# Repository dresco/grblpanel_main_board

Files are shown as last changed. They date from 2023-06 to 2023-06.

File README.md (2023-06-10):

# grblPANEL reference board

KiCad implementation of a grblPANEL control board, with the following features;
- up to 88 input keys
- up to 4 quadrature encoders
- display output (reference design using a 3.5" ILI9488 panel)
- Modbus and CAN bus (WIP) connectivity to grblHAL controller
- SWD connector (2x5 1.27mm) for programming and debugging
- USB C interface for programming and configuration (WIP)
- ESD protection on all user connections
- 5-12V DC power input - with reverse polarity, undervoltage, overvoltage, and overcurrent protection

The control board uses the following high level components;
- STM32G0 MCU running at 64MHz
- TI SN65HVD230 CAN transceiver
- TI THVD1406 Modbus transceiver
- Analog Devices ADP5589 I/O expander
- Analog Devices MAX17612A power protection IC

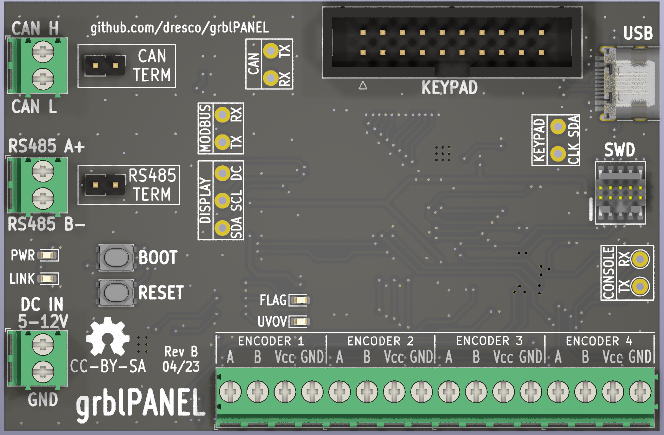
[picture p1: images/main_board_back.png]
back

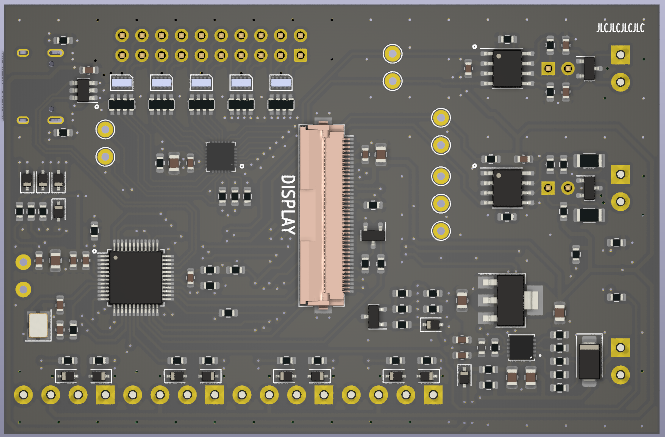
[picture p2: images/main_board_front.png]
front


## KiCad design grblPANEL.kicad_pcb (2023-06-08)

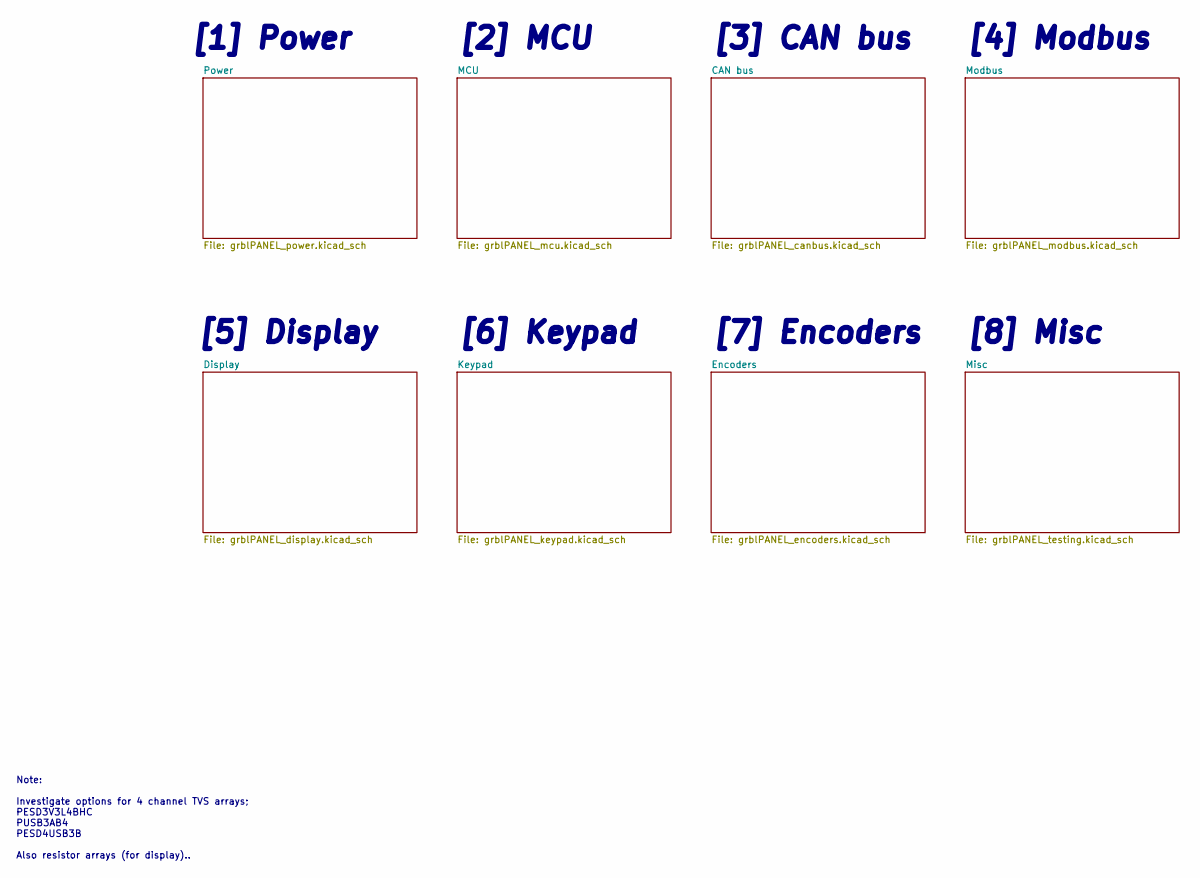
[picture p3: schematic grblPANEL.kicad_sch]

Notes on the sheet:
[2] MCU
[3] CAN bus
[1] Power
[8] Misc
Note: Investigate options for 4 channel TVS arrays; PESD3V3L4BHC PUSB3AB4 PESD4USB3B Also resistor arrays (for display)..
[6] Keypad
[4] Modbus
[5] Display
[7] Encoders

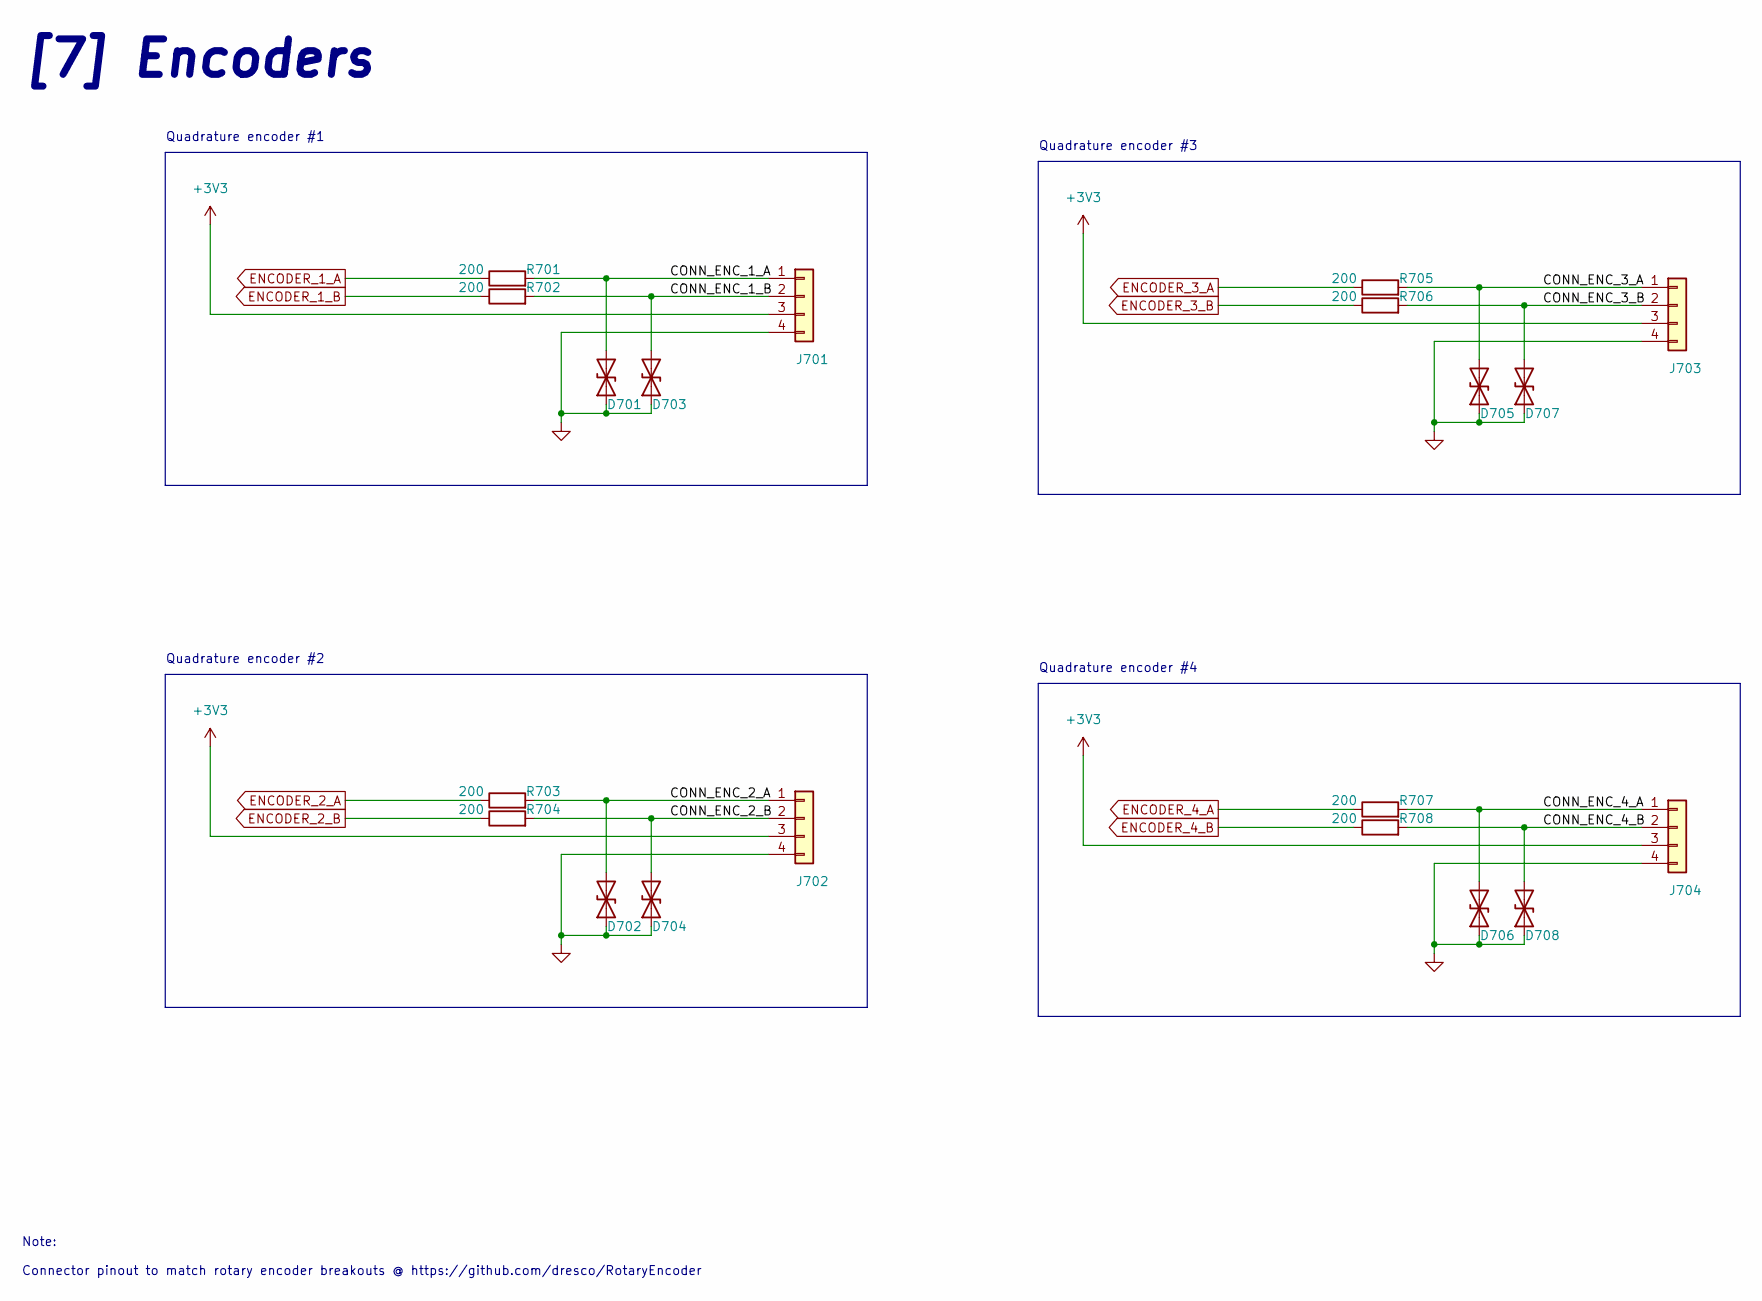
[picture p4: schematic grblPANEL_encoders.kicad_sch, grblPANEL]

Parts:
D701, D702, D703, D704, D705, D706, D707, D708: D_TVS; D_SOD-323
J701, J702, J703, J704: Conn_01x04; TerminalBlock_Phoenix_PT-1,5-4-3.5-H_1x04_P3.50mm_Horizontal
R701, R702, R703, R704, R705, R706, R707, R708: 200; R_0603_1608Metric

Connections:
+3V3: J701.3, J702.3, J703.3, J704.3; also elsewhere on the board
/Encoders/CONN_ENC_1_A: D701.2 (A2), J701.1, R701.2
/Encoders/CONN_ENC_1_B: D703.2 (A2), J701.2, R702.2
/Encoders/CONN_ENC_2_A: D702.2 (A2), J702.1, R703.2
/Encoders/CONN_ENC_2_B: D704.2 (A2), J702.2, R704.2
/Encoders/CONN_ENC_3_A: D705.2 (A2), J703.1, R705.2
/Encoders/CONN_ENC_3_B: D707.2 (A2), J703.2, R706.2
/Encoders/CONN_ENC_4_A: D706.2 (A2), J704.1, R707.2
/Encoders/CONN_ENC_4_B: D708.2 (A2), J704.2, R708.2
ENCODER_1_A: R701.1; also elsewhere on the board
ENCODER_1_B: R702.1; also elsewhere on the board
ENCODER_2_A: R703.1; also elsewhere on the board
ENCODER_2_B: R704.1; also elsewhere on the board
ENCODER_3_A: R705.1; also elsewhere on the board
ENCODER_3_B: R706.1; also elsewhere on the board
ENCODER_4_A: R707.1; also elsewhere on the board
ENCODER_4_B: R708.1; also elsewhere on the board
GND: D701.1 (A1), D702.1 (A1), D703.1 (A1), D704.1 (A1), D705.1 (A1), D706.1 (A1), D707.1 (A1), D708.1 (A1), J701.4, J702.4, J703.4, J704.4; also elsewhere on the board

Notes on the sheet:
Quadrature encoder #3
Quadrature encoder #1
[7] Encoders
Quadrature encoder #4
Quadrature encoder #2
Note: Connector pinout to match rotary encoder breakouts @ https://github.com/dresco/RotaryEncoder

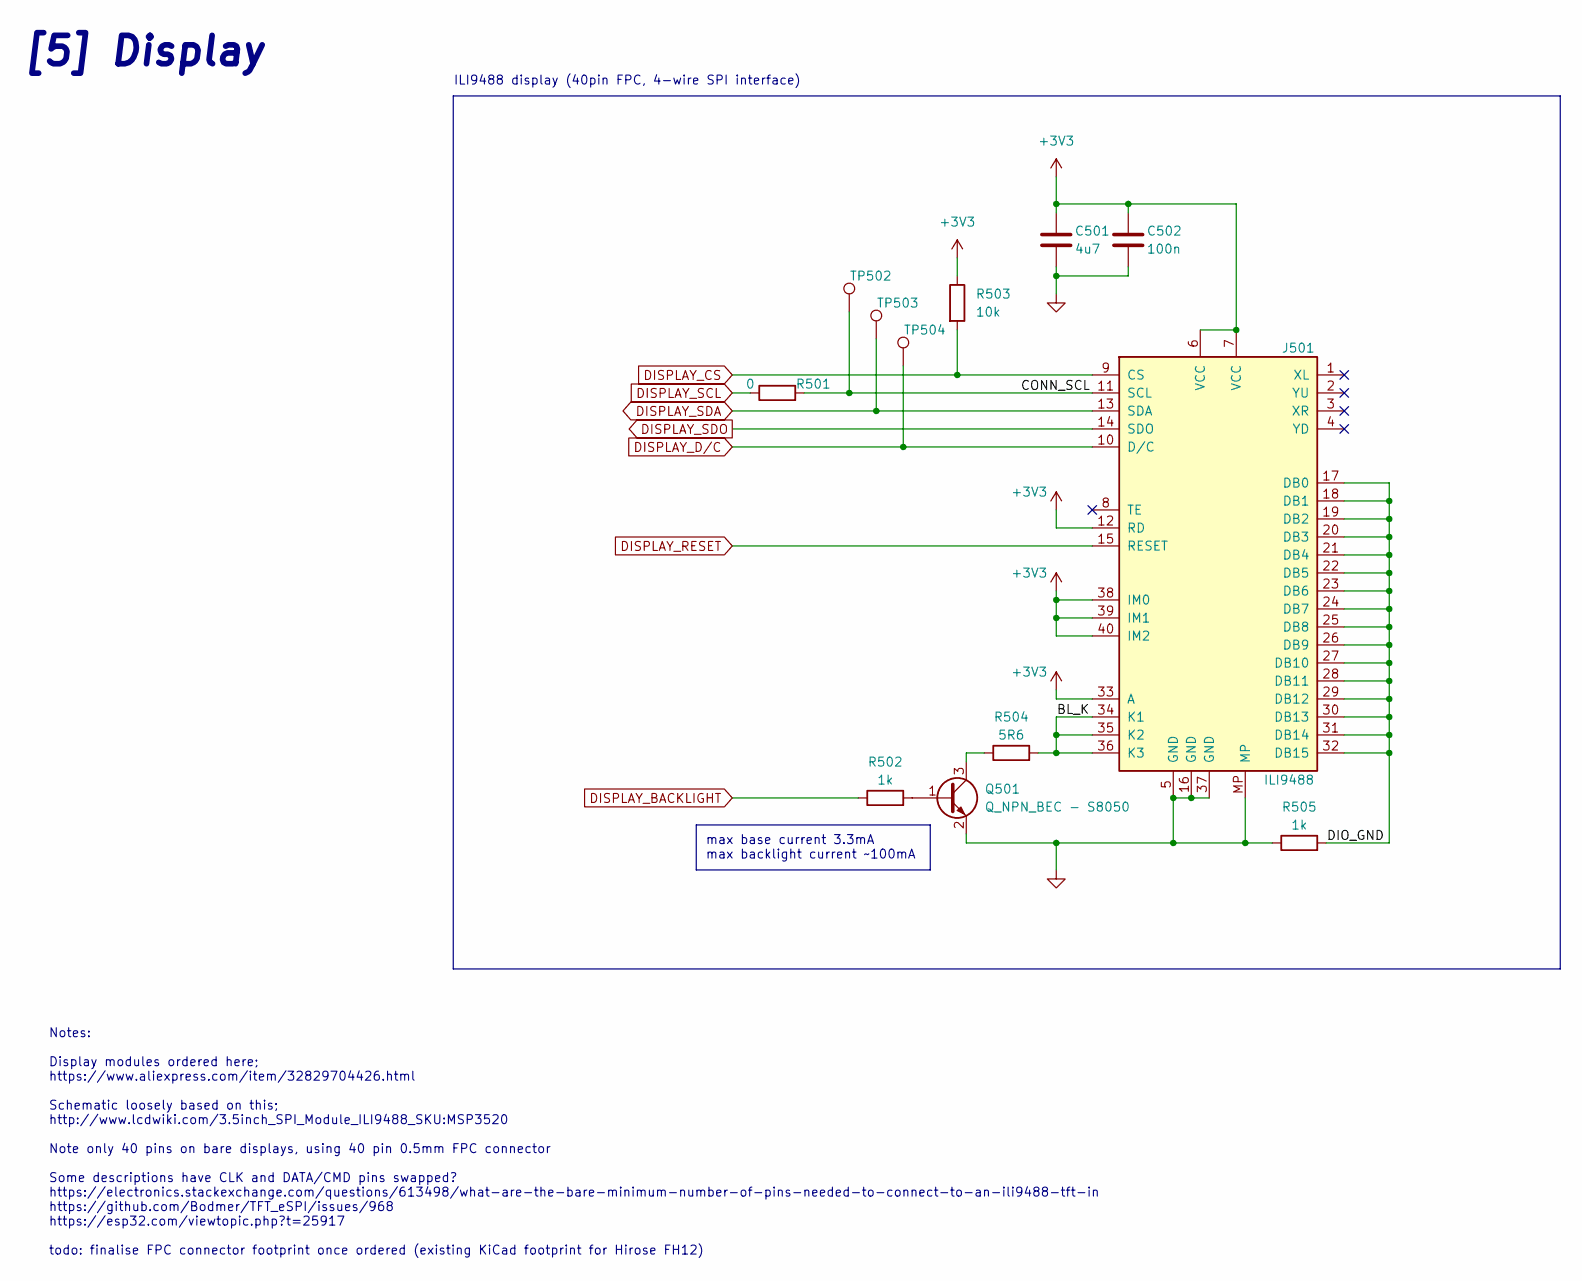
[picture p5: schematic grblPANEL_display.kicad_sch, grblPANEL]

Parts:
C501: 4u7; C_0805_2012Metric
C502: 100n; C_0603_1608Metric
J501: ILI9488; Hirose_FH12-40S-0.5SH_1x40-1MP_P0.50mm_Horizontal
Q501: Q_NPN_BEC - S8050; SOT-23
R501: 0; R_0603_1608Metric
R502, R505: 1k; R_0603_1608Metric
R503: 10k; R_0603_1608Metric
R504: 5R6; R_0603_1608Metric
TP502, TP503, TP504: TestPoint; TestPoint_THTPad_D2.0mm_Drill1.0mm

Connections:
+3V3: C501.1, C502.1, J501.6 (VCC), J501.7 (VCC), J501.12 (RD), J501.33 (A), J501.38 (IM0), J501.39 (IM1), J501.40 (IM2), R503.1; also elsewhere on the board
/Display/BL_K: J501.34 (K1), J501.35 (K2), J501.36 (K3), R504.2
/Display/CONN_SCL: J501.11 (SCL), R501.2, TP502.1
/Display/DIO_GND: J501.17 (DB0), J501.18 (DB1), J501.19 (DB2), J501.20 (DB3), J501.21 (DB4), J501.22 (DB5), J501.23 (DB6), J501.24 (DB7), J501.25 (DB8), J501.26 (DB9), J501.27 (DB10), J501.28 (DB11), J501.29 (DB12), J501.30 (DB13), J501.31 (DB14), J501.32 (DB15), R505.2
DISPLAY_BACKLIGHT: R502.1; also elsewhere on the board
DISPLAY_CS: J501.9 (CS), R503.2; also elsewhere on the board
DISPLAY_D/C: J501.10 (D/C), TP504.1; also elsewhere on the board
DISPLAY_RESET: J501.15 (RESET); also elsewhere on the board
DISPLAY_SCL: R501.1; also elsewhere on the board
DISPLAY_SDA: J501.13 (SDA), TP503.1; also elsewhere on the board
DISPLAY_SDO: J501.14 (SDO); also elsewhere on the board
GND: C501.2, C502.2, J501.5 (GND), J501.16 (GND), J501.37 (GND), J501.MP, Q501.2 (E), R505.1; also elsewhere on the board
unnamed: Q501.1 (B), R502.2
unnamed: Q501.3 (C), R504.1

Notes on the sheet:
[5] Display
max base current 3.3mA max backlight current ~100mA
Notes: Display modules ordered here; https://www.aliexpress.com/item/32829704426.html Schematic loosely based on this; http://www.lcdwiki.com/3.5inch_SPI_Module_ILI9488_SKU:MSP3520 Note only 40 pins on bare displays, using 40 pin 0.5mm FPC connector Some descriptions have CLK and DATA/CMD pins swap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
ILI9488 display (40pin FPC, 4-wire SPI interface)

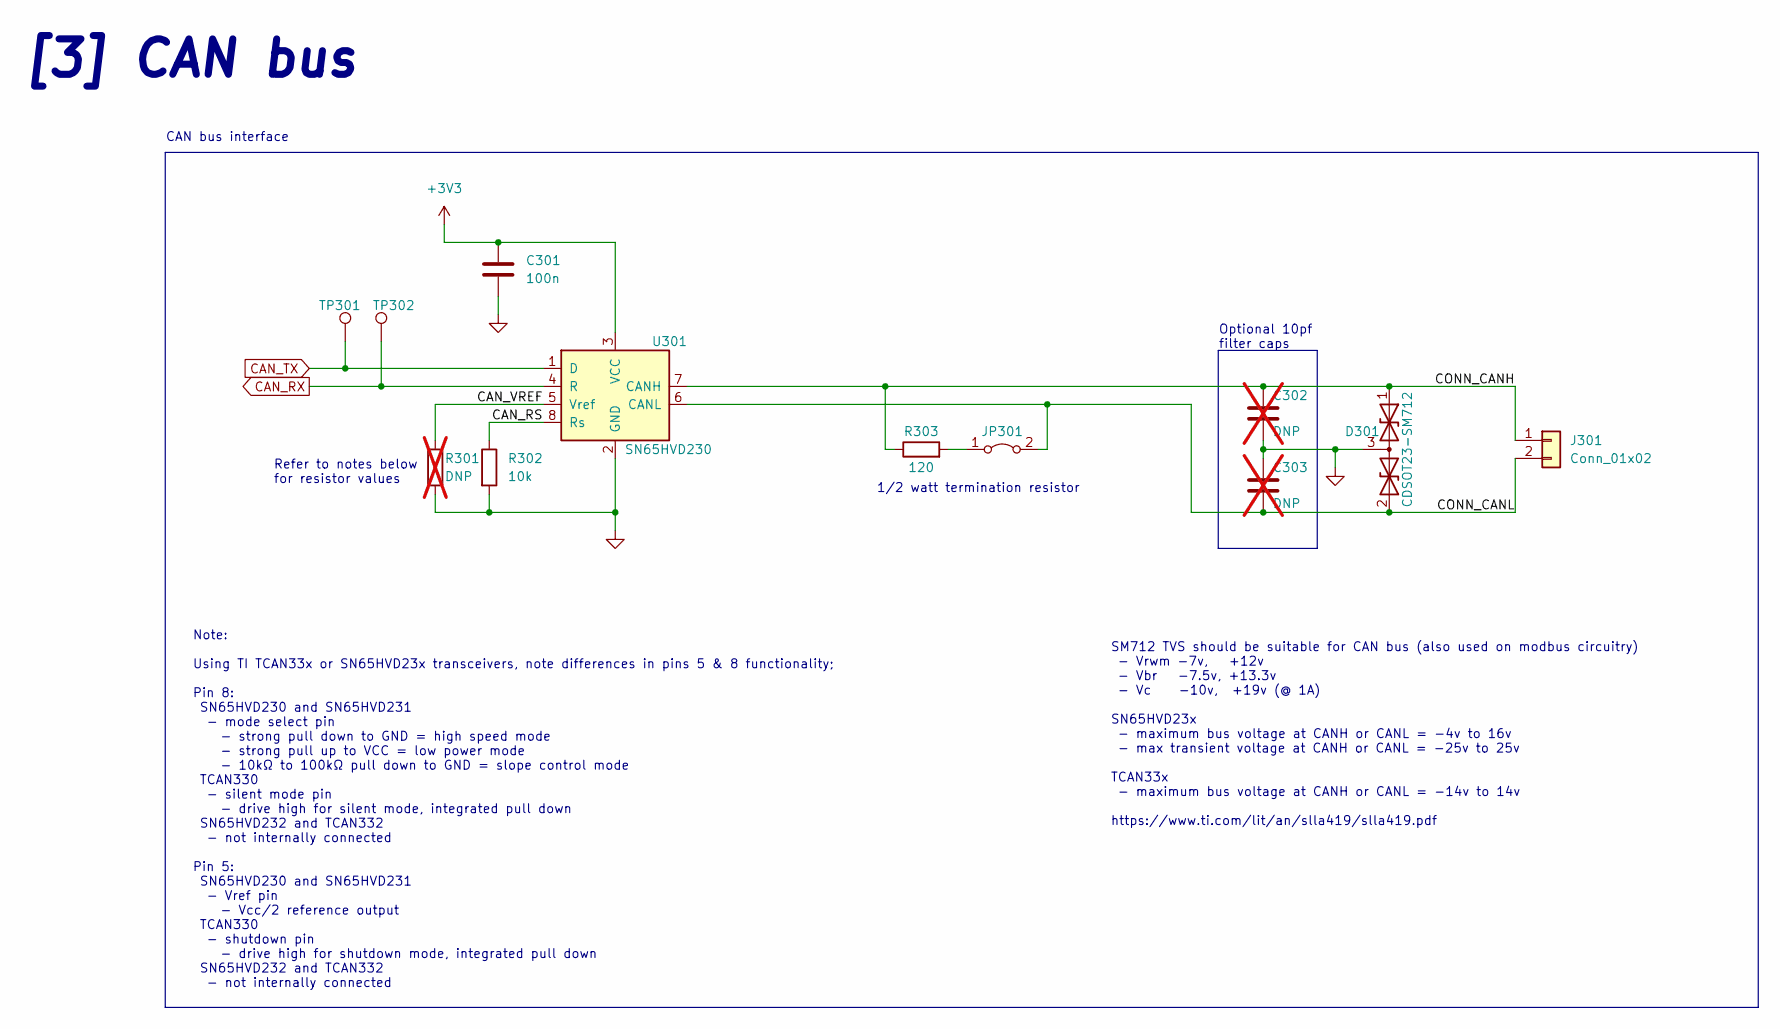
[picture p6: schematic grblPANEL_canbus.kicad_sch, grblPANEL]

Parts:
C301: 100n; C_0603_1608Metric
C302, C303: DNP; C_0603_1608Metric; not fitted
D301: CDSOT23-SM712; SOT-23
J301: Conn_01x02; TerminalBlock_Phoenix_PT-1,5-2-3.5-H_1x02_P3.50mm_Horizontal
JP301: Jumper_2_Bridged; PinHeader_1x02_P2.54mm_Vertical
R301: DNP; R_0603_1608Metric; not fitted
R302: 10k; R_0603_1608Metric
R303: 120; R_0603_1608Metric
TP301, TP302: TestPoint; TestPoint_THTPad_D2.0mm_Drill1.0mm
U301: SN65HVD230; SOIC-8_3.9x4.9mm_P1.27mm

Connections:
+3V3: C301.1, U301.3 (VCC); also elsewhere on the board
/CAN bus/CAN_RS: R302.1, U301.8 (Rs)
/CAN bus/CAN_VREF: R301.1, U301.5 (Vref)
/CAN bus/CONN_CANH: C302.1, D301.1 (A1), J301.1, R303.1, U301.7 (CANH)
/CAN bus/CONN_CANL: C303.2, D301.2 (A2), J301.2, JP301.2 (B), U301.6 (CANL)
CAN_RX: TP302.1, U301.4 (R); also elsewhere on the board
CAN_TX: TP301.1, U301.1 (D); also elsewhere on the board
GND: C301.2, C302.2, C303.1, D301.3 (common), R301.2, R302.2, U301.2 (GND); also elsewhere on the board
unnamed: JP301.1 (A), R303.2

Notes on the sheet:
Note: Using TI TCAN33x or SN65HVD23x transceivers, note differences in pins 5 & 8 functionality; Pin 8: SN65HVD230 and SN65HVD231 - mode select pin - strong pull down to GND = high speed mode - strong pull up to VCC = low power mode - 10kΩ to 100kΩ pull down to GND = slope control mode TCAN330 - si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
[3] CAN bus
CAN bus interface
SM712 TVS should be suitable for CAN bus (also used on modbus circuitry) - Vrwm -7v, +12v - Vbr -7.5v, +13.3v - Vc -10v, +19v (@ 1A) SN65HVD23x - maximum bus voltage at CANH or CANL = -4v to 16v - max transient voltage at CANH or CANL = -25v to 25v TCAN33x - maximum bus voltage at CANH or CANL = -1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
Refer to notes below for resistor values
1/2 watt termination resistor
Optional 10pf filter caps

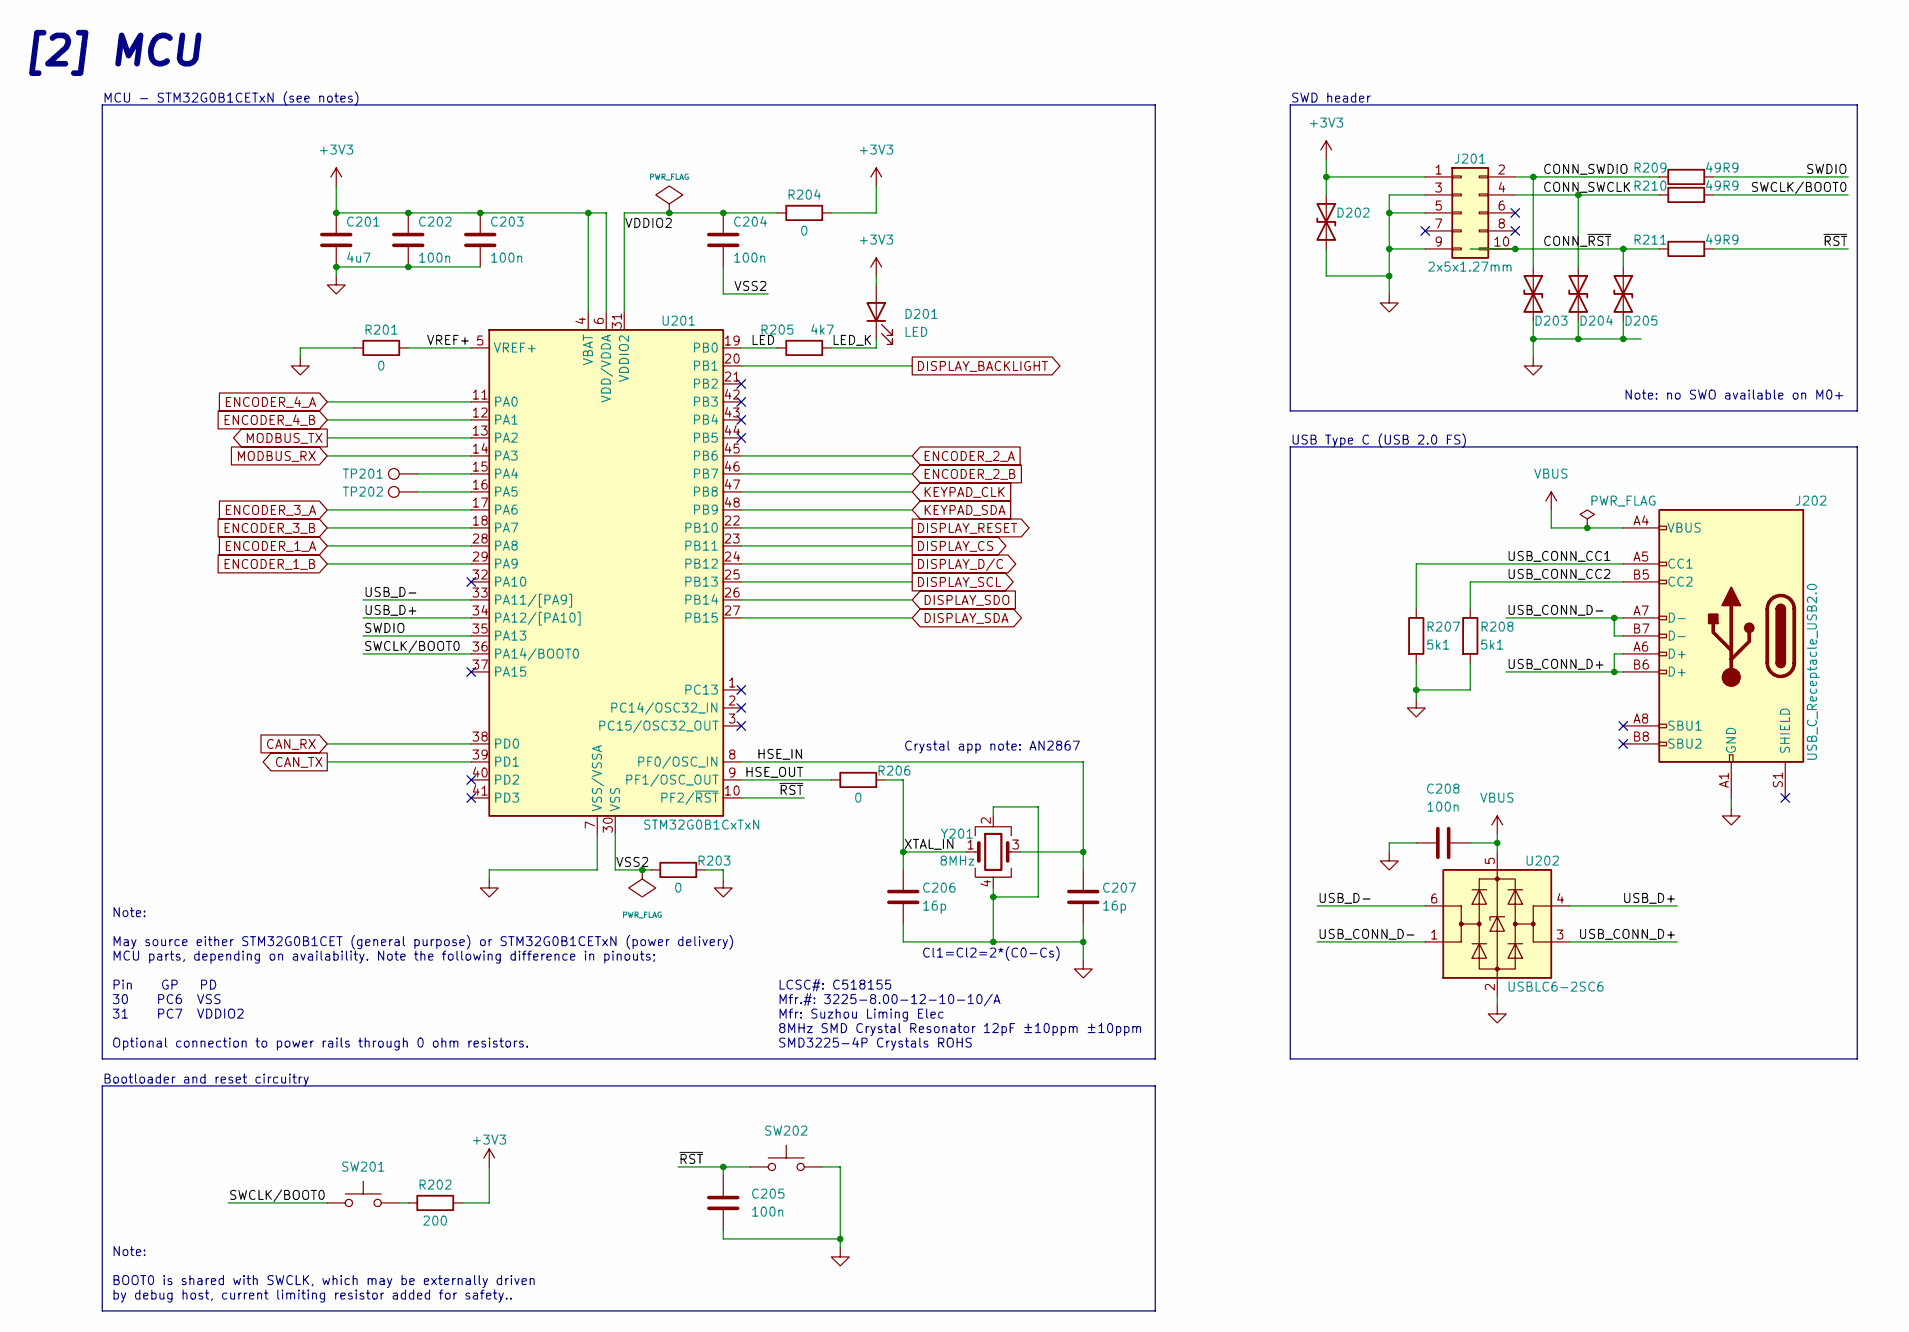
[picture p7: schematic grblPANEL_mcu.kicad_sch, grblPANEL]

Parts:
C201: 4u7; C_0805_2012Metric
C202, C203, C204, C205, C208: 100n; C_0603_1608Metric
C206, C207: 16p; C_0603_1608Metric
D201: LED; LED_0603_1608Metric
D202, D203, D204, D205: D_TVS; D_SOD-323
J201: 2x5x1.27mm; FTSH-105-01-L-DV-K
J202: USB_C_Receptacle_USB2.0; USB_C_Receptacle_HRO_TYPE-C-31-M-12
R201, R203, R204, R206: 0; R_0603_1608Metric
R202: 200; R_0603_1608Metric
R205: 4k7; R_0603_1608Metric
R207, R208: 5k1; R_0603_1608Metric
R209, R210, R211: 49R9; R_0603_1608Metric
SW201, SW202: SW_Push; SW_SPST_PTS810
TP201, TP202: TestPoint; TestPoint_THTPad_D2.0mm_Drill1.0mm
U201: STM32G0B1CxTxN; LQFP-48_7x7mm_P0.5mm
U202: USBLC6-2SC6; SOT-23-6
Y201: 8MHz; Crystal_SMD_3225-4Pin_3.2x2.5mm

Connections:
+3V3: C201.1, C202.1, C203.1, D201.2 (A), D202.1 (A1), J201.1, R202.2, R204.2, U201.4 (VBAT), U201.6 (VDD/VDDA); also elsewhere on the board
/MCU/CONN_SWCLK: D204.1 (A1), J201.4, R210.1
/MCU/CONN_SWDIO: D203.1 (A1), J201.2, R209.1
/MCU/CONN_~RST: D205.1 (A1), J201.10, R211.1
/MCU/HSE_IN: C207.1, U201.8 (PF0/OSC_IN), Y201.3
/MCU/HSE_OUT: R206.1, U201.9 (PF1/OSC_OUT)
/MCU/LED: R205.1, U201.19 (PB0)
/MCU/LED_K: D201.1 (K), R205.2
/MCU/SWCLK/BOOT0: R210.2, SW201.1, U201.36 (PA14/BOOT0)
/MCU/SWDIO: R209.2, U201.35 (PA13)
/MCU/USB_CONN_CC1: J202.A5 (CC1), R207.1
/MCU/USB_CONN_CC2: J202.B5 (CC2), R208.1
/MCU/USB_CONN_D+: J202.A6 (D+), J202.B6 (D+), U202.3 (I/O2)
/MCU/USB_CONN_D-: J202.A7 (D-), J202.B7 (D-), U202.1 (I/O1)
/MCU/USB_D+: U201.34 (PA12/[PA10]), U202.4 (I/O2)
/MCU/USB_D-: U201.33 (PA11/[PA9]), U202.6 (I/O1)
/MCU/VDDIO2: C204.1, R204.1, U201.31 (VDDIO2)
/MCU/VREF+: R201.2, U201.5 (VREF+)
/MCU/VSS2: C204.2, R203.1, U201.30 (VSS)
/MCU/XTAL_IN: C206.1, R206.2, Y201.1
/MCU/~RST: C205.1, R211.2, SW202.1, U201.10 (PF2/~RST)
CAN_RX: U201.38 (PD0); also elsewhere on the board
CAN_TX: U201.39 (PD1); also elsewhere on the board
DISPLAY_BACKLIGHT: U201.20 (PB1); also elsewhere on the board
DISPLAY_CS: U201.23 (PB11); also elsewhere on the board
DISPLAY_D/C: U201.24 (PB12); also elsewhere on the board
DISPLAY_RESET: U201.22 (PB10); also elsewhere on the board
DISPLAY_SCL: U201.25 (PB13); also elsewhere on the board
DISPLAY_SDA: U201.27 (PB15); also elsewhere on the board
DISPLAY_SDO: U201.26 (PB14); also elsewhere on the board
ENCODER_1_A: U201.28 (PA8); also elsewhere on the board
ENCODER_1_B: U201.29 (PA9); also elsewhere on the board
ENCODER_2_A: U201.45 (PB6); also elsewhere on the board
ENCODER_2_B: U201.46 (PB7); also elsewhere on the board
ENCODER_3_A: U201.17 (PA6); also elsewhere on the board
ENCODER_3_B: U201.18 (PA7); also elsewhere on the board
ENCODER_4_A: U201.11 (PA0); also elsewhere on the board
ENCODER_4_B: U201.12 (PA1); also elsewhere on the board
GND: C201.2, C202.2, C203.2, C205.2, C206.2, C207.2, C208.1, D202.2 (A2), D203.2 (A2), D204.2 (A2), D205.2 (A2), J201.3, J201.5, J201.9, J202.A1 (GND), J202.A12 (GND), J202.B1 (GND), J202.B12 (GND), R201.1, R203.2, R207.2, R208.2, SW202.2, U201.7 (VSS/VSSA), U202.2 (GND), Y201.2, Y201.4; also elsewhere on the board
KEYPAD_CLK: U201.47 (PB8); also elsewhere on the board
KEYPAD_SDA: U201.48 (PB9); also elsewhere on the board
MODBUS_RX: U201.14 (PA3); also elsewhere on the board
MODBUS_TX: U201.13 (PA2); also elsewhere on the board
unnamed: R202.1, SW201.2
unnamed: TP201.1, U201.15 (PA4)
unnamed: TP202.1, U201.16 (PA5)
VBUS: C208.2, J202.A4 (VBUS), J202.A9 (VBUS), J202.B4 (VBUS), J202.B9 (VBUS), U202.5 (VBUS); also elsewhere on the board

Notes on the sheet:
Note: BOOT0 is shared with SWCLK, which may be externally driven by debug host, current limiting resistor added for safety..
Cl1=Cl2=2*(C0-Cs)
Bootloader and reset circuitry
Crystal app note: AN2867
[2] MCU
MCU - STM32G0B1CETxN (see notes)
Note: May source either STM32G0B1CET (general purpose) or STM32G0B1CETxN (power delivery) MCU parts, depending on availability. Note the following difference in pinouts; Pin GP PD 30 PC6 VSS 31 PC7 VDDIO2 Optional connection to power rails through 0 ohm resistors.
LCSC#: C518155 Mfr.#: 3225-8.00-12-10-10/A Mfr: Suzhou Liming Elec 8MHz SMD Crystal Resonator 12pF ±10ppm ±10ppm SMD3225-4P Crystals ROHS
Note: no SWO available on M0+
USB Type C (USB 2.0 FS)
SWD header

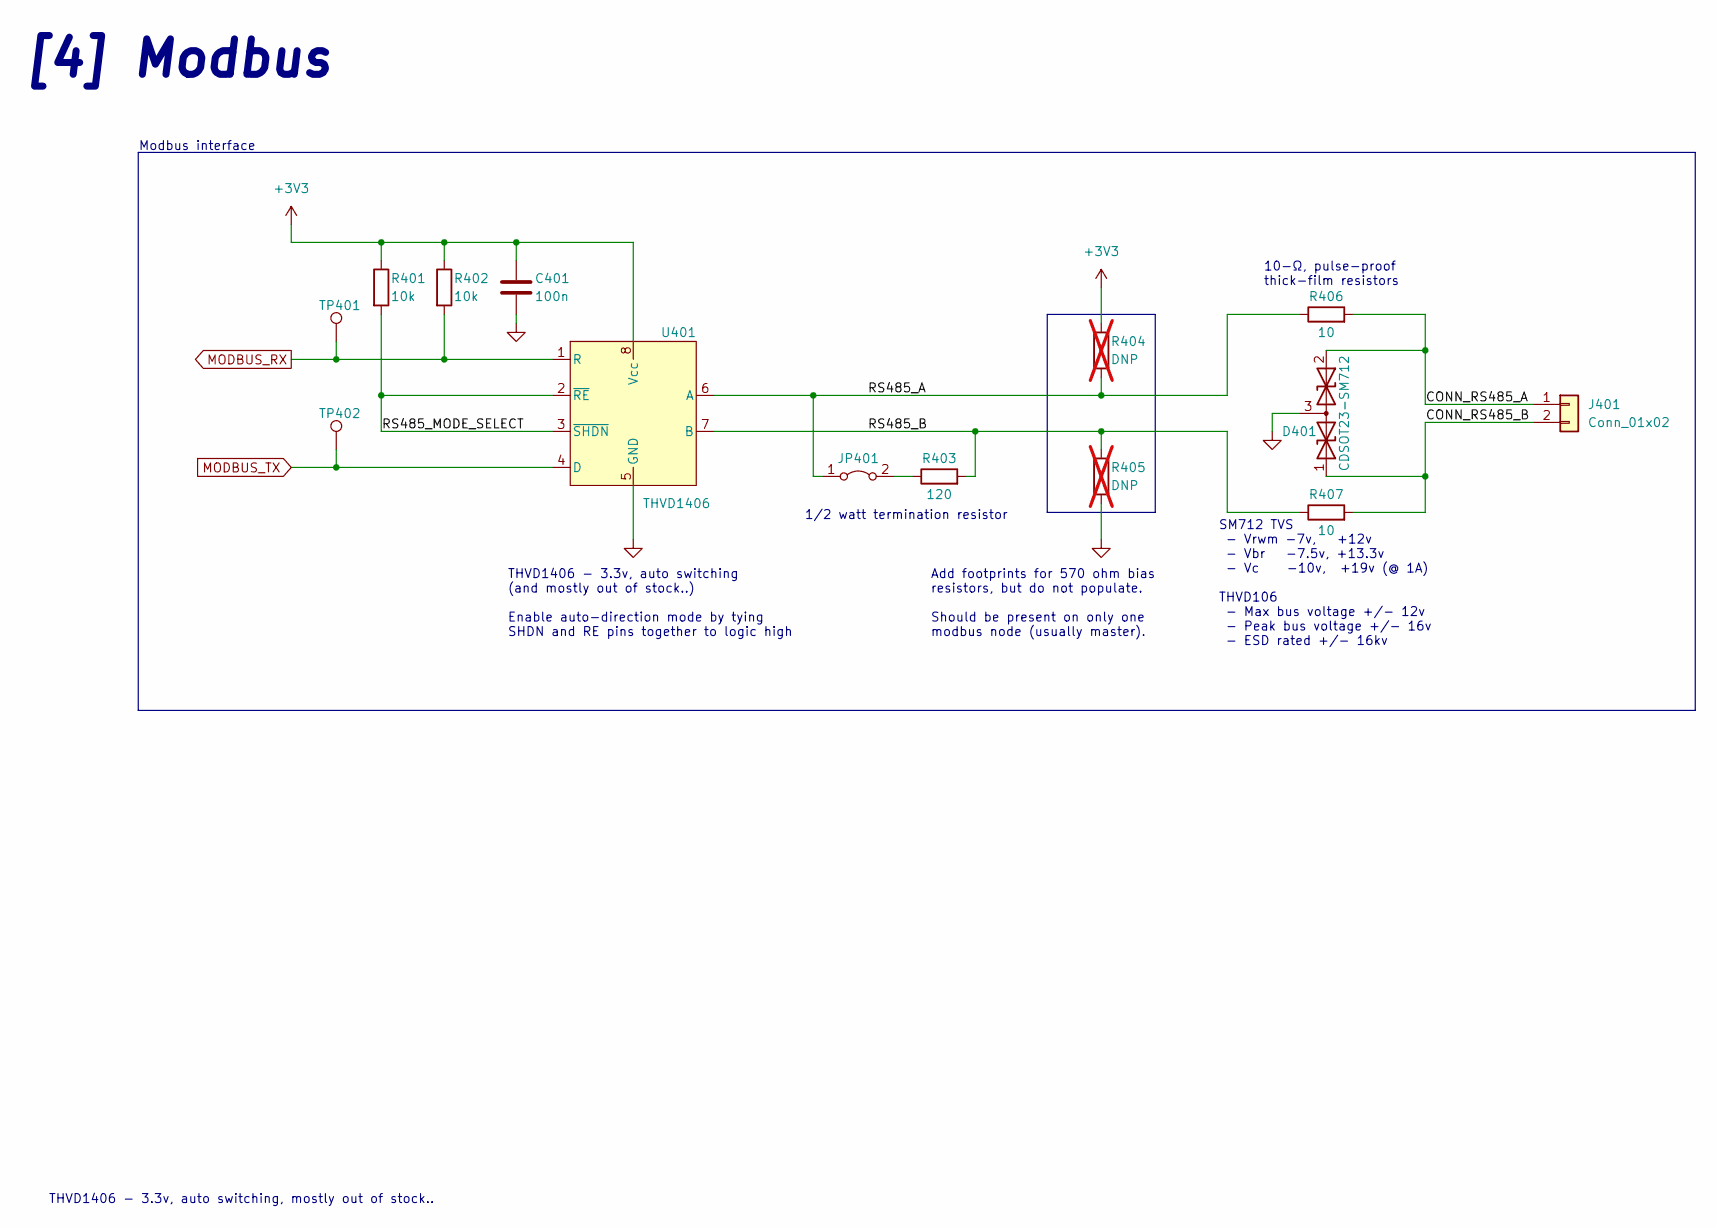
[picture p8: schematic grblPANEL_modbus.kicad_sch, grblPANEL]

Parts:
C401: 100n; C_0603_1608Metric
D401: CDSOT23-SM712; SOT-23
J401: Conn_01x02; TerminalBlock_Phoenix_PT-1,5-2-3.5-H_1x02_P3.50mm_Horizontal
JP401: Jumper_2_Bridged; PinHeader_1x02_P2.54mm_Vertical
R401, R402: 10k; R_0603_1608Metric
R403: 120; R_0603_1608Metric
R404, R405: DNP; R_0603_1608Metric; not fitted
R406, R407: 10; R_1206_3216Metric
TP401, TP402: TestPoint; TestPoint_THTPad_D2.0mm_Drill1.0mm
U401: THVD1406; SOIC-8_3.9x4.9mm_P1.27mm

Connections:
+3V3: C401.1, R401.1, R402.1, R404.1, U401.8 (Vcc); also elsewhere on the board
/Modbus/CONN_RS485_A: D401.2 (A2), J401.1, R406.2
/Modbus/CONN_RS485_B: D401.1 (A1), J401.2, R407.2
/Modbus/RS485_A: JP401.1 (A), R404.2, R406.1, U401.6 (A)
/Modbus/RS485_B: R403.2, R405.1, R407.1, U401.7 (B)
/Modbus/RS485_MODE_SELECT: R401.2, U401.2 (~RE), U401.3 (~SHDN)
GND: C401.2, D401.3 (common), R405.2, U401.5 (GND); also elsewhere on the board
MODBUS_RX: R402.2, TP401.1, U401.1 (R); also elsewhere on the board
MODBUS_TX: TP402.1, U401.4 (D); also elsewhere on the board
unnamed: JP401.2 (B), R403.1

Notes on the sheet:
THVD1406 - 3.3v, auto switching (and mostly out of stock..) Enable auto-direction mode by tying SHDN and RE pins together to logic high
[4] Modbus
Modbus interface
THVD1406 - 3.3v, auto switching, mostly out of stock..
Add footprints for 570 ohm bias resistors, but do not populate. Should be present on only one modbus node (usually master).
SM712 TVS - Vrwm -7v, +12v - Vbr -7.5v, +13.3v - Vc -10v, +19v (@ 1A) THVD106 - Max bus voltage +/- 12v - Peak bus voltage +/- 16v - ESD rated +/- 16kv
1/2 watt termination resistor
10-Ω, pulse-proof thick-film resistors

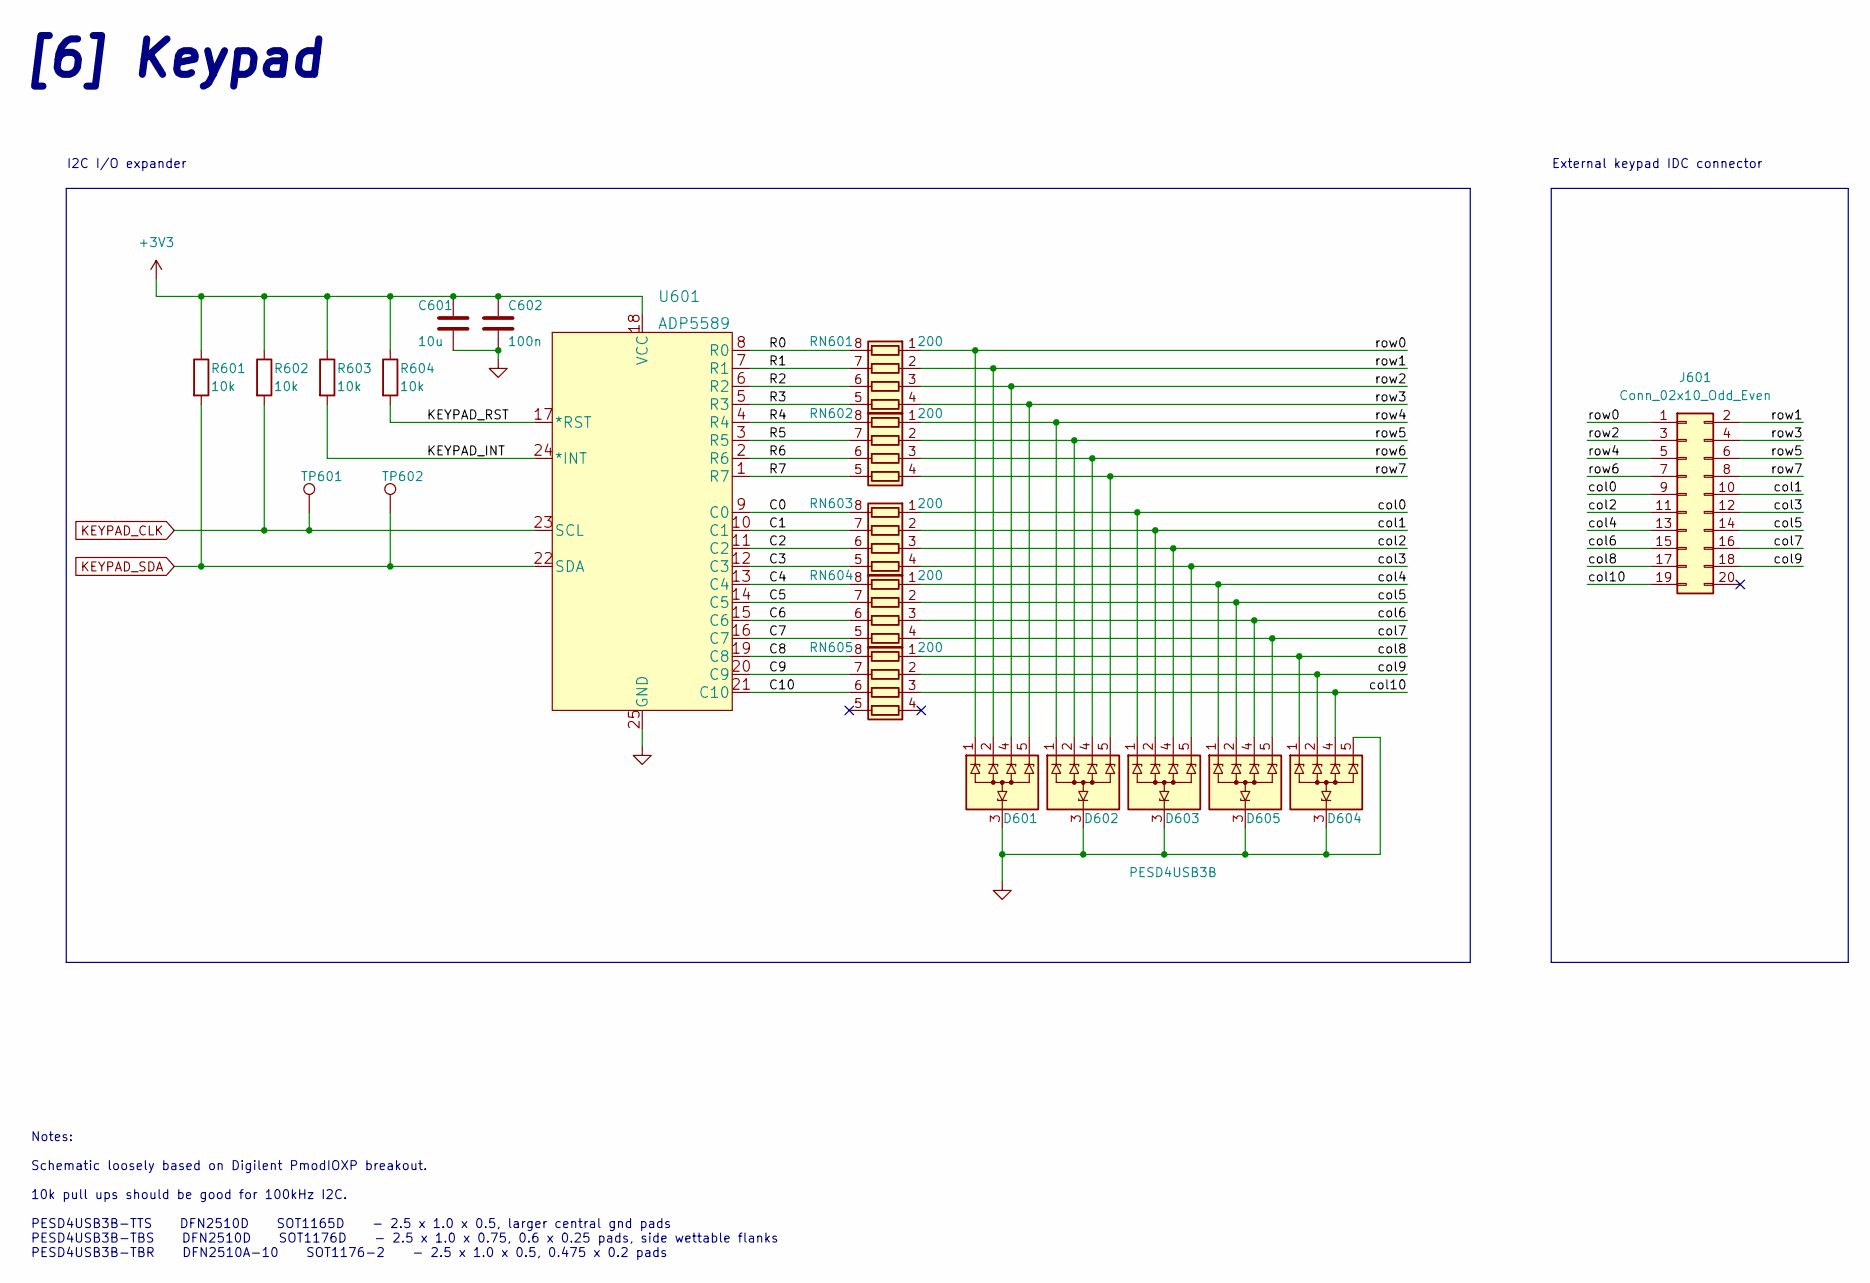
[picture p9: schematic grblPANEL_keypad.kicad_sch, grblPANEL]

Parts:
C601: 10u; C_0805_2012Metric
C602: 100n; C_0603_1608Metric
D601, D602, D603, D604, D605: PESD4USB3B; SOT1176D
J601: Conn_02x10_Odd_Even; IDC-Header_2x10_P2.54mm_Vertical
R601, R602, R603, R604: 10k; R_0603_1608Metric
RN601, RN602, RN603, RN604, RN605: 200; R_Array_Convex_4x0603
TP601, TP602: TestPoint; TestPoint_THTPad_D2.0mm_Drill1.0mm
U601: ADP5589; LFCSP-24-1EP_3.5x3.5mm_P0.4mm_EP2.2x2.2mm_ThermalVias

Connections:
+3V3: C601.1, C602.1, R601.1, R602.1, R603.1, R604.1, U601.18 (VCC); also elsewhere on the board
/Keypad/C0: RN603.8 (R1.2), U601.9 (C0)
/Keypad/C1: RN603.7 (R2.2), U601.10 (C1)
/Keypad/C2: RN603.6 (R3.2), U601.11 (C2)
/Keypad/C3: RN603.5 (R4.2), U601.12 (C3)
/Keypad/C4: RN604.8 (R1.2), U601.13 (C4)
/Keypad/C5: RN604.7 (R2.2), U601.14 (C5)
/Keypad/C6: RN604.6 (R3.2), U601.15 (C6)
/Keypad/C7: RN604.5 (R4.2), U601.16 (C7)
/Keypad/C8: RN605.8 (R1.2), U601.19 (C8)
/Keypad/C9: RN605.7 (R2.2), U601.20 (C9)
/Keypad/C10: RN605.6 (R3.2), U601.21 (C10)
/Keypad/KEYPAD_INT: R603.2, U601.24 (*INT)
/Keypad/KEYPAD_RST: R604.2, U601.17 (*RST)
/Keypad/R0: RN601.8 (R1.2), U601.8 (R0)
/Keypad/R1: RN601.7 (R2.2), U601.7 (R1)
/Keypad/R2: RN601.6 (R3.2), U601.6 (R2)
/Keypad/R3: RN601.5 (R4.2), U601.5 (R3)
/Keypad/R4: RN602.8 (R1.2), U601.4 (R4)
/Keypad/R5: RN602.7 (R2.2), U601.3 (R5)
/Keypad/R6: RN602.6 (R3.2), U601.2 (R6)
/Keypad/R7: RN602.5 (R4.2), U601.1 (R7)
/Keypad/col0: D603.1 (TVS1), D603.10 (TVS1), J601.9, RN603.1 (R1.1)
/Keypad/col1: D603.2 (TVS2), D603.9 (TVS2), J601.10, RN603.2 (R2.1)
/Keypad/col2: D603.4 (TVS3), D603.7 (TVS3), J601.11, RN603.3 (R3.1)
/Keypad/col3: D603.5 (TVS4), D603.6 (TVS4), J601.12, RN603.4 (R4.1)
/Keypad/col4: D604.1 (TVS1), D604.10 (TVS1), J601.13, RN604.1 (R1.1)
/Keypad/col5: D604.2 (TVS2), D604.9 (TVS2), J601.14, RN604.2 (R2.1)
/Keypad/col6: D604.4 (TVS3), D604.7 (TVS3), J601.15, RN604.3 (R3.1)
/Keypad/col7: D604.5 (TVS4), D604.6 (TVS4), J601.16, RN604.4 (R4.1)
/Keypad/col8: D605.1 (TVS1), D605.10 (TVS1), J601.17, RN605.1 (R1.1)
/Keypad/col9: D605.2 (TVS2), D605.9 (TVS2), J601.18, RN605.2 (R2.1)
/Keypad/col10: D605.4 (TVS3), D605.7 (TVS3), J601.19, RN605.3 (R3.1)
/Keypad/row0: D601.1 (TVS1), D601.10 (TVS1), J601.1, RN601.1 (R1.1)
/Keypad/row1: D601.2 (TVS2), D601.9 (TVS2), J601.2, RN601.2 (R2.1)
/Keypad/row2: D601.4 (TVS3), D601.7 (TVS3), J601.3, RN601.3 (R3.1)
/Keypad/row3: D601.5 (TVS4), D601.6 (TVS4), J601.4, RN601.4 (R4.1)
/Keypad/row4: D602.1 (TVS1), D602.10 (TVS1), J601.5, RN602.1 (R1.1)
/Keypad/row5: D602.2 (TVS2), D602.9 (TVS2), J601.6, RN602.2 (R2.1)
/Keypad/row6: D602.4 (TVS3), D602.7 (TVS3), J601.7, RN602.3 (R3.1)
/Keypad/row7: D602.5 (TVS4), D602.6 (TVS4), J601.8, RN602.4 (R4.1)
GND: C601.2, C602.2, D601.3 (GND), D601.8 (GND), D602.3 (GND), D602.8 (GND), D603.3 (GND), D603.8 (GND), D604.3 (GND), D604.8 (GND), D605.3 (GND), D605.5 (TVS4), D605.6 (TVS4), D605.8 (GND), U601.25 (GND); also elsewhere on the board
KEYPAD_CLK: R602.2, TP601.1, U601.23 (SCL); also elsewhere on the board
KEYPAD_SDA: R601.2, TP602.1, U601.22 (SDA); also elsewhere on the board

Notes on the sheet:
I2C I/O expander
[6] Keypad
External keypad IDC connector
Notes: Schematic loosely based on Digilent PmodIOXP breakout. 10k pull ups should be good for 100kHz I2C. PESD4USB3B-TTS DFN2510D SOT1165D - 2.5 x 1.0 x 0.5, larger central gnd pads PESD4USB3B-TBS DFN2510D SOT1176D - 2.5 x 1.0 x 0.75, 0.6 x 0.25 pads, side wettable flanks PESD4USB3B-TBR DFN2510A-10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

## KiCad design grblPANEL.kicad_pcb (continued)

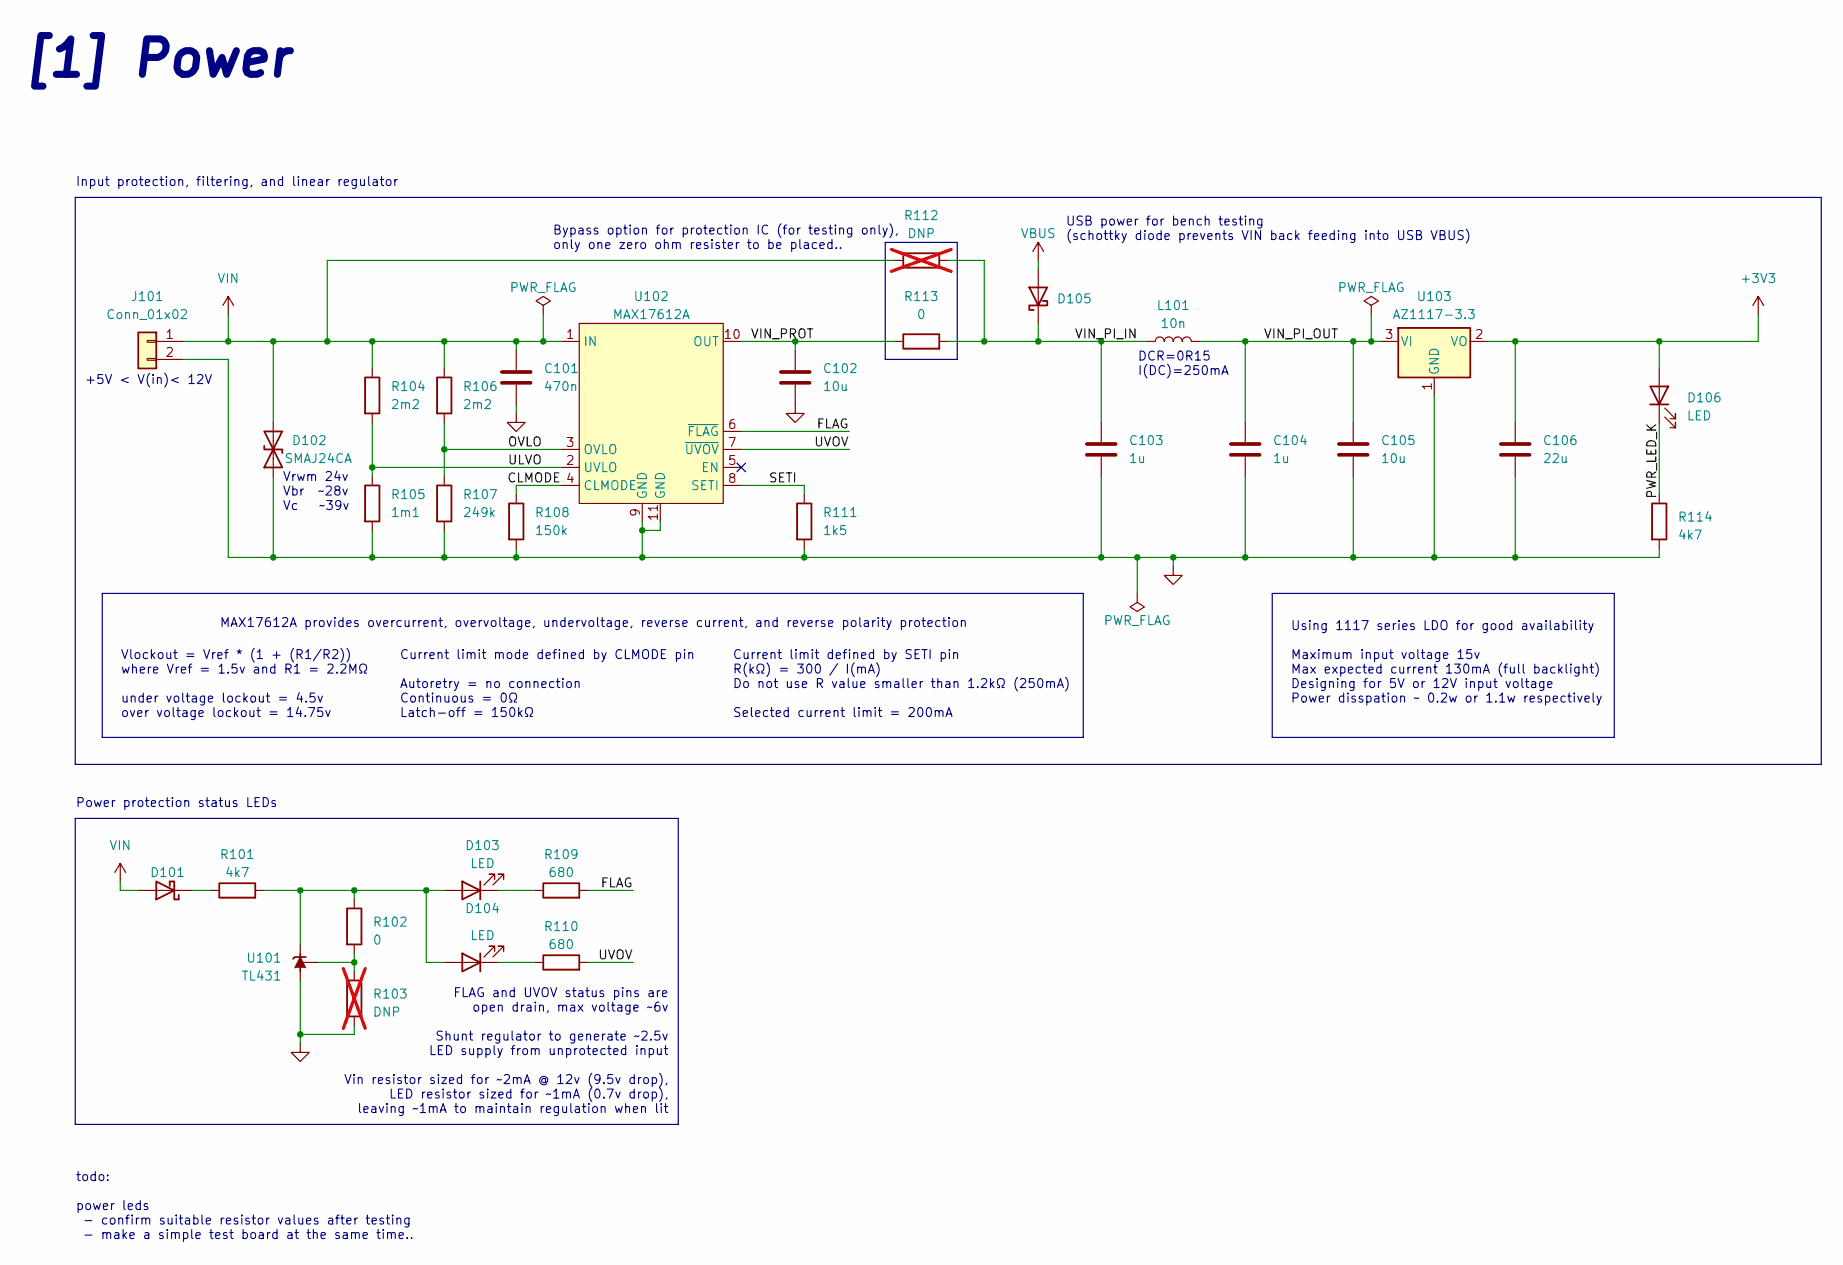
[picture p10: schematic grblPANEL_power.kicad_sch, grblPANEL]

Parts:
C101: 470n; C_0805_2012Metric
C102, C105: 10u; C_0805_2012Metric
C103, C104: 1u; C_0603_1608Metric
C106: 22u; C_0805_2012Metric
D101, D105: D_Schottky; D_SOD-323
D102: SMAJ24CA; D_SMA
D103, D104, D106: LED; LED_0603_1608Metric
J101: Conn_01x02; TerminalBlock_Phoenix_PT-1,5-2-3.5-H_1x02_P3.50mm_Horizontal
L101: 10n; L_0603_1608Metric
R101, R114: 4k7; R_0603_1608Metric
R102, R113: 0; R_0603_1608Metric
R103, R112: DNP; R_0603_1608Metric; not fitted
R104, R106: 2m2; R_0603_1608Metric
R105: 1m1; R_0603_1608Metric
R107: 249k; R_0603_1608Metric
R108: 150k; R_0603_1608Metric
R109, R110: 680; R_0603_1608Metric
R111: 1k5; R_0603_1608Metric
U101: TL431; SOT-23
U102: MAX17612A; TDFN-10-1EP_3x3mm_P0.5mm_EP1.6x2.39mm_ThermalVias
U103: AZ1117-3.3; SOT-223-3_TabPin2

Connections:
+3V3: C106.1, D106.2 (A), U103.2 (VO); also elsewhere on the board
/Power/CLMODE: R108.1, U102.4 (CLMODE)
/Power/FLAG: R109.2, U102.6 (~FLAG)
/Power/OVLO: R106.2, R107.1, U102.3 (OVLO)
/Power/PWR_LED_K: D106.1 (K), R114.1
/Power/SETI: R111.1, U102.8 (SETI)
/Power/ULVO: R104.2, R105.1, U102.2 (UVLO)
/Power/UVOV: R110.2, U102.7 (~UVOV)
/Power/VIN_PI_IN: C103.1, D105.1 (K), L101.1, R112.2, R113.2
/Power/VIN_PI_OUT: C104.1, C105.1, L101.2, U103.3 (VI)
/Power/VIN_PROT: C102.1, R113.1, U102.10 (OUT)
GND: C101.2, C102.2, C103.2, C104.2, C105.2, C106.2, D102.1 (A1), J101.2, R103.2, R105.2, R107.2, R108.2, R111.2, R114.2, U101.3 (A), U102.9 (GND), U102.11 (GND), U103.1 (GND); also elsewhere on the board
unnamed: D101.1 (K), R101.1
unnamed: D103.2 (A), D104.2 (A), R101.2, R102.1, U101.1 (K)
unnamed: D103.1 (K), R109.1
unnamed: D104.1 (K), R110.1
unnamed: R102.2, R103.1, U101.2 (REF)
VBUS: D105.2 (A); also elsewhere on the board
VIN: C101.1, D101.2 (A), D102.2 (A2), J101.1, R104.1, R106.1, R112.1, U102.1 (IN)

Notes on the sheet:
+5V < V(in)< 12V
USB power for bench testing (schottky diode prevents VIN back feeding into USB VBUS)
Using 1117 series LDO for good availability Maximum input voltage 15v Max expected current 130mA (full backlight) Designing for 5V or 12V input voltage Power disspation ~ 0.2w or 1.1w respectively
MAX17612A provides overcurrent, overvoltage, undervoltage, reverse current, and reverse polarity protection
Input protection, filtering, and linear regulator
FLAG and UVOV status pins are open drain, max voltage ~6v Shunt regulator to generate ~2.5v LED supply from unprotected input Vin resistor sized for ~2mA @ 12v (9.5v drop), LED resistor sized for ~1mA (0.7v drop), leaving ~1mA to maintain regulation when lit
Bypass option for protection IC (for testing only), only one zero ohm resister to be placed..
Current limit defined by SETI pin R(kΩ) = 300 / I(mA) Do not use R value smaller than 1.2kΩ (250mA) Selected current limit = 200mA
Power protection status LEDs
Vrwm 24v Vbr ~28v Vc ~39v
[1] Power
Current limit mode defined by CLMODE pin Autoretry = no connection Continuous = 0Ω Latch-off = 150kΩ
Vlockout = Vref * (1 + (R1/R2)) where Vref = 1.5v and R1 = 2.2MΩ under voltage lockout = 4.5v over voltage lockout = 14.75v
DCR=0R15 I(DC)=250mA
todo: power leds - confirm suitable resistor values after testing - make a simple test board at the same time..

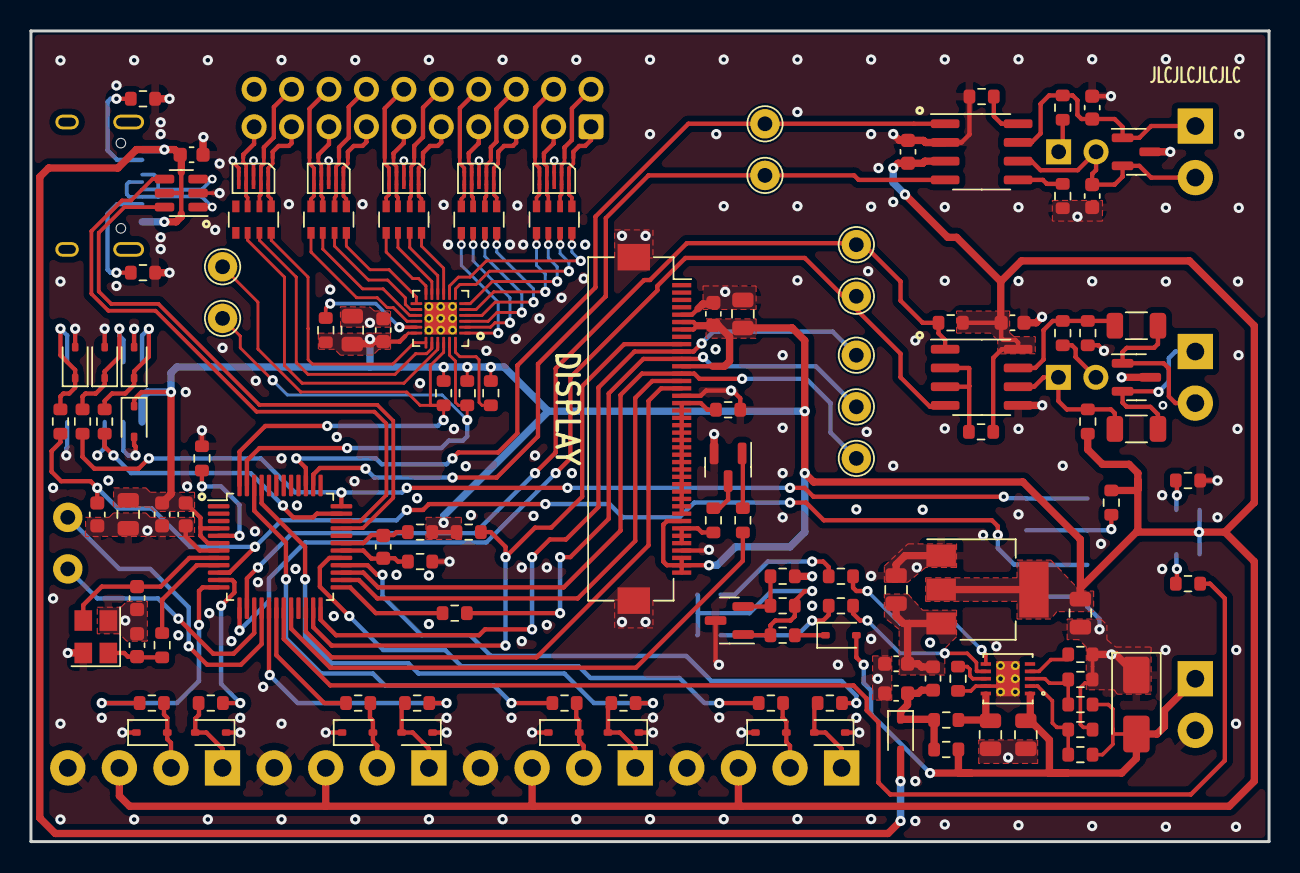
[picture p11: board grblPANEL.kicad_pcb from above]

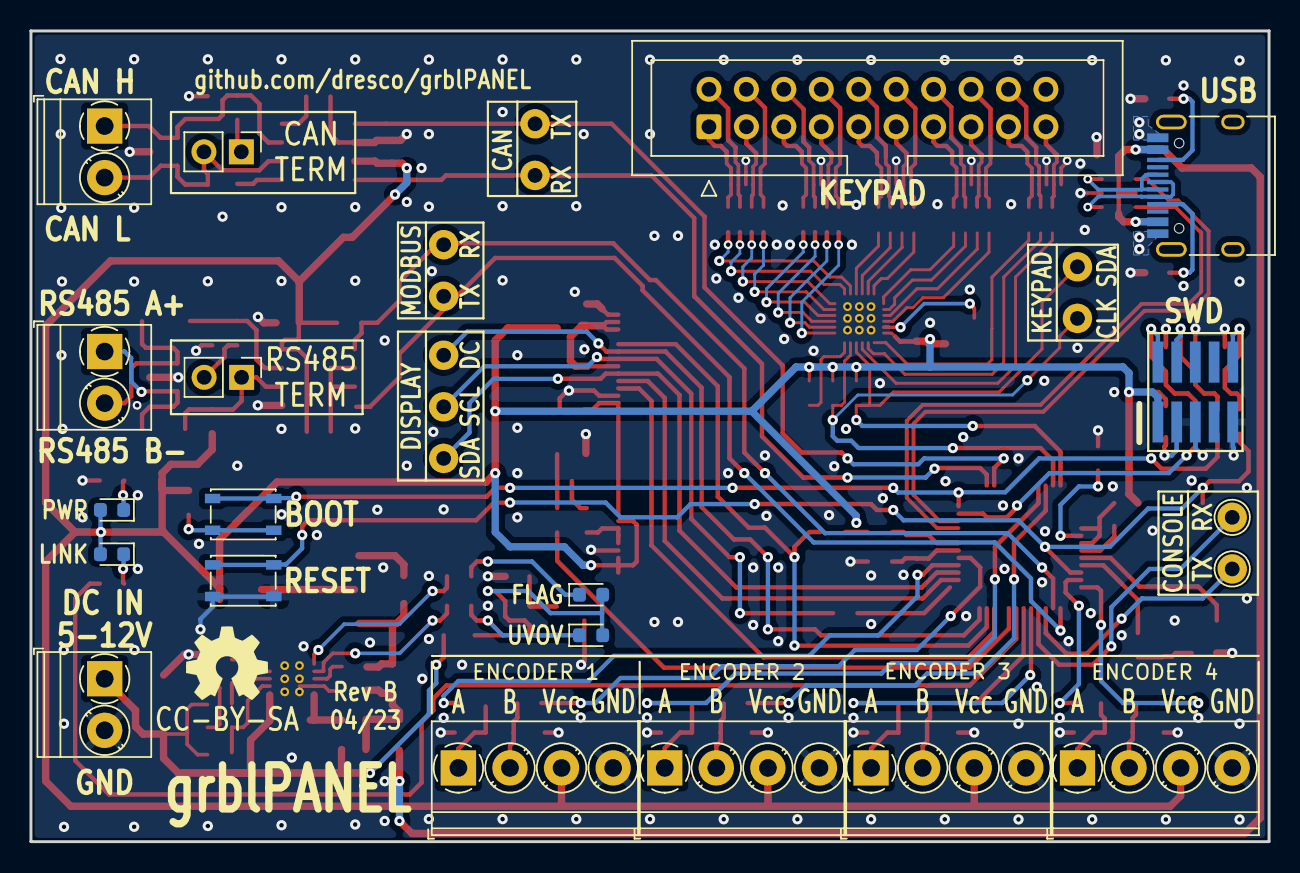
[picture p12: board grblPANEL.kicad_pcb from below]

Board: 4 copper layers, 84.0 x 55.0 mm, 142 parts (20 on the bottom side), 127 nets.

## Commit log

2022-12-09 ERC fixes
    [grblPANEL.kicad_sch, grblPANEL_canbus.kicad_sch, grblPANEL_display.kicad_sch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]
2022-12-16 Status LED & annotation cleanup
    [grblPANEL.kicad_sch, grblPANEL_encoders.kicad_sch, grblPANEL_mcu.kicad_sch]
2022-12-16 Weeny schematic update
    [grblPANEL_mcu.kicad_sch]
2022-12-16 Initial PCB setup & rules
    [grblPANEL.kicad_pcb]
2022-12-20 PCB layout - WIP
    [grblPANEL.kicad_pcb, grblPANEL.kicad_sch, grblPANEL_canbus.kicad_sch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]
2022-12-22 WIP layout
    [grblPANEL.kicad_pcb, grblPANEL.kicad_sch, grblPANEL_display.kicad_sch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]
2022-12-22 Resistor & TVS arrays
    [grblPANEL.kicad_pcb, grblPANEL.kicad_sch, grblPANEL_keypad.kicad_sch]
2023-01-03 1st stab at routing power input section
    [grblPANEL.kicad_pcb, grblPANEL_keypad.kicad_sch]
2023-01-03 1st stab at routing can interface
    [grblPANEL.kicad_pcb]
2023-01-03 1st stab at modbus interface routing
    [grblPANEL.kicad_pcb]
2023-01-04 1st stab at keypad + usb routing
    [grblPANEL.kicad_pcb]
2023-01-04 bit more usb..
    [grblPANEL.kicad_pcb]
2023-01-06 some mcu..
    [grblPANEL.kicad_pcb, grblPANEL_display.kicad_sch]
2023-01-06 1st crack at display routing
    [grblPANEL.kicad_pcb, grblPANEL_mcu.kicad_sch]
2023-01-06 modbus cleanup
    [grblPANEL.kicad_pcb, grblPANEL_modbus.kicad_sch]
2023-01-07 power section cleanup change 1206 caps to 0805
    [grblPANEL.kicad_pcb, grblPANEL.kicad_sch, grblPANEL_keypad.kicad_sch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]
2023-01-07 reset & bootloader buttons
    [grblPANEL.kicad_pcb, grblPANEL.kicad_sch, grblPANEL_mcu.kicad_sch]
2023-01-08 more routing
    [grblPANEL.kicad_pcb, grblPANEL_mcu.kicad_sch]
2023-01-08 bit more routing buttons etc
    [grblPANEL.kicad_pcb]
2023-01-08 initial routing complete, pending test points & cleanup
    [grblPANEL.kicad_pcb]
2023-01-08 Ensure silkscreen is not covering holes
    [grblPANEL.kicad_pcb]
2023-01-17 small cleanups
    [grblPANEL.kicad_pcb, grblPANEL.kicad_sch, grblPANEL_canbus.kicad_sch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]
2023-01-17 place gnd vias near all signal and power vias
    [grblPANEL.kicad_pcb]
2023-01-17 sheet 1 test points
    [grblPANEL.kicad_pcb, grblPANEL.kicad_sch, grblPANEL_power.kicad_sch]
2023-01-17 canbus & modbus test points
    [grblPANEL.kicad_pcb, grblPANEL.kicad_sch, grblPANEL_canbus.kicad_sch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]
2023-01-17 keypad test points
    [grblPANEL.kicad_pcb, grblPANEL.kicad_sch, grblPANEL_display.kicad_sch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]
2023-01-17 stiching vias
    [grblPANEL.kicad_pcb]
2023-01-17 arrange fab layer text
    [grblPANEL.kicad_pcb]
2023-01-17 Back side silkscreen - labels etc..
    [grblPANEL.kicad_pcb]
2023-01-17 bit more silkscreen
    [grblPANEL.kicad_pcb]
2023-01-18 jlc placement text
    [grblPANEL.kicad_pcb]
2023-01-18 silkscreen - id pin 1 where missing
    [grblPANEL.kicad_pcb]
2023-01-18 bit more silk
    [grblPANEL.kicad_pcb]
2023-01-18 add thermal relief to internal ground planes
    [grblPANEL.kicad_pcb]
2023-01-18 set zone priority of power puddles
    [grblPANEL.kicad_pcb]
2023-01-18 outer layer ground pour and custom rule
    needs additional custom rule to prevent the
    ground pour from inheriting the tigher clearances
    from erlier custom rules (as zone is within affected
    courtyards)
    note weird interactions with GND power puddles if adding
    thermal reliefs
    [grblPANEL.kicad_pcb]
2023-01-18 remove outer pours..
    ..while considering what to do about the power puddles
    [grblPANEL.kicad_pcb]
2023-01-18 output settings for jlcpcb
    [grblPANEL.kicad_pcb]
2023-01-19 Add Rev A manufacturing files
    [grblPANEL-B_Cu.gbl, grblPANEL-B_Mask.gbs, grblPANEL-B_Paste.gbp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]
2023-01-19 Add mounting pads to ILI9488 connector symbol
    Tied to ground plane in schematic and pcb
    [grblPANEL.kicad_pcb, grblPANEL_display.kicad_sch]
2023-01-19 tweak ILI9488 mounting pads
    add copper pour to bottom layer
    [grblPANEL.kicad_pcb]
2023-01-19 Updated Rev A manufacturing files
    Copper pours on outer layers
    [grblPANEL-B_Cu.gbl, grblPANEL-B_Mask.gbs, grblPANEL-B_Paste.gbp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]
2023-06-08 v7 upgrade
    schematic symbols updated from libraries
    pcb update from schematic
    update footprints from library
    board setup, thermal relief count
    still DRC warnings where symbols have been updated locally with 3d
    models etc
    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
    [grblPANEL.kicad_pcb, grblPANEL.kicad_sch, grblPANEL_canbus.kicad_sch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]
2023-06-08 Move display flex connector
    Move keypad connector & protection to create clearance.
    Moved display connector 2.7mm towards board edge to reduce strain
    on the flex connector.
    Minor tidy up..
    [grblPANEL.kicad_pcb]
2023-06-08 Schematic: add usart6 connector on pa4/pa5
    will be used for console log output
    [grblPANEL_mcu.kicad_sch]
2023-06-08 Add power protection status LEDs
    [grblPANEL_mcu.kicad_sch, grblPANEL_power.kicad_sch]
2023-06-08 Board changes for Rev B
    Import changes from schematic.
    Place and route changes from schematic:
    Headers for serial console.
    DNP components to v7 format.
    Power status components.
    LEDs to bottom side, plus silkscreen.
    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
    [grblPANEL.kicad_pcb, grblPANEL.kicad_sch, grblPANEL_canbus.kicad_sch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]
2023-06-08 Increase 0.25/0.55mm vias to 0.30/0.60mm
    (JLC price bump for 0.25 drill holes)
    Final tweaks before submitting
    [grblPANEL-B_Cu.gbl, grblPANEL-B_Mask.gbs, grblPANEL-B_Paste.gbp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]
2023-06-08 RevB manufacturing files
    [grblPANEL-B_Cu.gbl, grblPANEL-B_Mask.gbs, grblPANEL-B_Paste.gbp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]
2023-06-08 Green LED resistor changes
    Reduce the intensity of the green status LEDs, resistors changed
    from 1k to 4k7
    [grblPANEL.kicad_pcb, grblPANEL_mcu.kicad_sch, grblPANEL_power.kicad_sch]

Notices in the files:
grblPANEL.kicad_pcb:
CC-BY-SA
